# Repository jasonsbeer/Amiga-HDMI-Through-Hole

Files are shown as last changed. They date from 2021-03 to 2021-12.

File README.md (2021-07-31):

# Amiga Video Slot to HDMI with Through Hole Components
This project was inspired by the [Amiga Digital Video](https://github.com/c0pperdragon/Amiga-Digital-Video) project by c0pperdragon. This design makes use of the Amiga 2000/3000 video slot and easy to solder through hole components, making it friendly for even the novice DIYer. At the time of writing this, all the components are available through DigiKey. This has been tested with both standard and Super Denise on Amiga 2000 rev 4.x and 6.x boards. The picture output is outstanding. It should be fully compatable with the Amiga 3000, but I do not have access to one for testing.

There are mounting holes to facilitate the use of a support bracket, which can be 3D printed. The bracket files can be found [here](/STL).

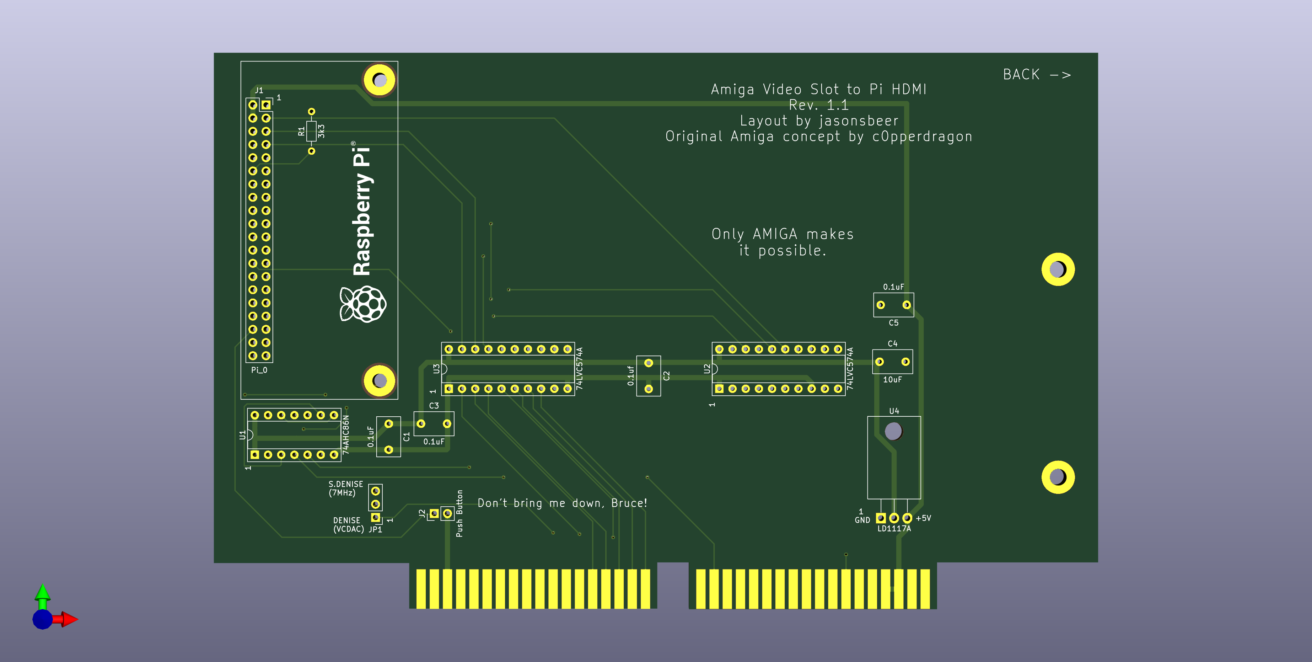
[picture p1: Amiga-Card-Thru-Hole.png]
Video Card Image


## PCB Ordering
The gerber files are available in the [Gerber](/Gerber) folder. Download the file and send to your preferred PCB manufacturer. I've been ordering mine through JLCPCB and have been happy with the results. Most of the options will be set directly from the Gerber file. For the rest, you can select these [options](JLCPCB-1.png).

## PCB Assembly
Order parts from the BOM list. I have included DigiKey part numbers for reference. Solder the components to the board, noting orientation of the sockets. You can solder the chips directly to the board, but I do not recommend this for DIY projects.

### v1.1 BOM
|Component|Package|Location|QTY|Source|Part Number|
--- | --- | --- | --- | --- | ---
SN74AHC86|14-DIP|U1|1|DigiKey|296-4627-5-ND
SN74AHC574|20-DIP|U2-3|2|DigiKey|296-4616-5-ND
LD1117AV33|TO-220-3|U4|1|DigiKey|497-1485-5-ND
14-DIP Socket|14-DIP|U1|1|DigiKey|AE9989-ND
20-DIP Socket|20-DIP|U2-3|2|DigiKey|AE9998-ND
0.1uF Ceramic Capacitor|Radial|C1-3,5|4|DigiKey|399-14065-1-ND
10uF Ceramic Capacitor|Radial|C4|1|DigiKey|445-181284-1-ND
40 Position Female Header|-|J1|1|DigiKey|S6104-ND
3x1 Male Header|-|JP1|1|DigiKey|732-5316-ND
Jumper|-|JP1|1|DigiKey|609-6251-ND
2x1 Male Header|-|J2|1|DigiKey|732-5315-ND
3.3k Resistor|Axial|R1|1|DigiKey|3.3KQBK-ND
Panel Mount HDMI Cable (optional)|-|-|1|DigiKey|1528-1575-ND
HDMI Mini to HDMI Adapter (optional)|-|-|1|DigiKey|1528-2481-ND

## Using The Card
You will need to supply a Raspberry Pi Zero and copy the correct program to a micro-SD card for the Pi to run. The standard (non-W) version of the Pi Zero works fine and is cheaper. You can obtain the current software release from the [RGBtoHDMI](https://github.com/hoglet67/RGBtoHDMI/releases) project page. Click on the link of the newest release, scroll to the bottom of the page, and download the zip file. Unzip and copy the files to the micro SD card and insert the micro SD card in the Pi Zero. Attach the Pi Zero to the video card, making sure to double check the orientation. The Pi Zero should be installed "face down", with pin 1 towards the "top" of the card. Installing the Pi incorrectly will likely kill it.

Set JP1 to match the Denise version in your Amiga. S.Denise = Super Denise (CSG 8373) or Denise (MOS 8362). An incorrect jumper setting will result in a low quality image. Connect an HDMI cable to the Raspberri Pi and to an HDMI or DVI monitor. If you do not have a support bracket, I strongly encourage you to place a peice of thin cardboard between the video card and the power supply of the Amiga 2000. Tape it in place to ensure the card will not short out on the power supply housing.

A momentary push button switch may be attached at J2 that will allow access to settings of the Pi software.

## Revision History
v1.0 Initial production release

v1.1 Routed /C1 and /C3 to U1. Delete U5 and R2

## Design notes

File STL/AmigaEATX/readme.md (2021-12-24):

These are the STL and FreeCAD files used to print a bracket in order to use this card in the Amiga 2000 EATX (https://github.com/jasonsbeer/Amiga-2000-EATX). It includes a mounting for a momentary pushbutton switch (7.2mm cutout) and HDMI panel mount socket.

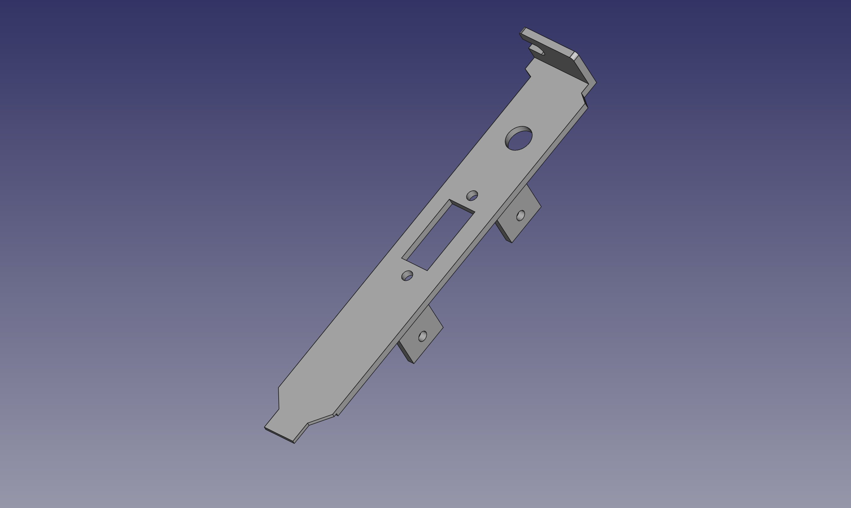
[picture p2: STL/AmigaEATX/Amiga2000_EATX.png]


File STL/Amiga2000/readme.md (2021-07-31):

These are the STL and FreeCAD files for a video slot bracket for this card. Designed specifically for the Amiga 2000, it may also work in an Amiga 3000. It includes a mounting for a momentary pushbutton switch (7.2mm cutout) and HDMI panel mount socket.

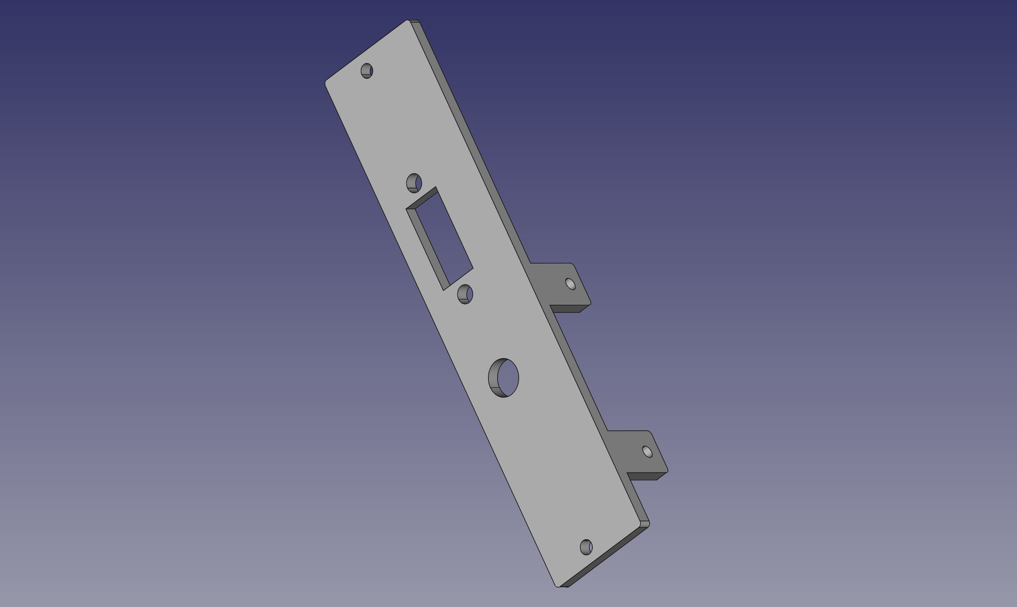
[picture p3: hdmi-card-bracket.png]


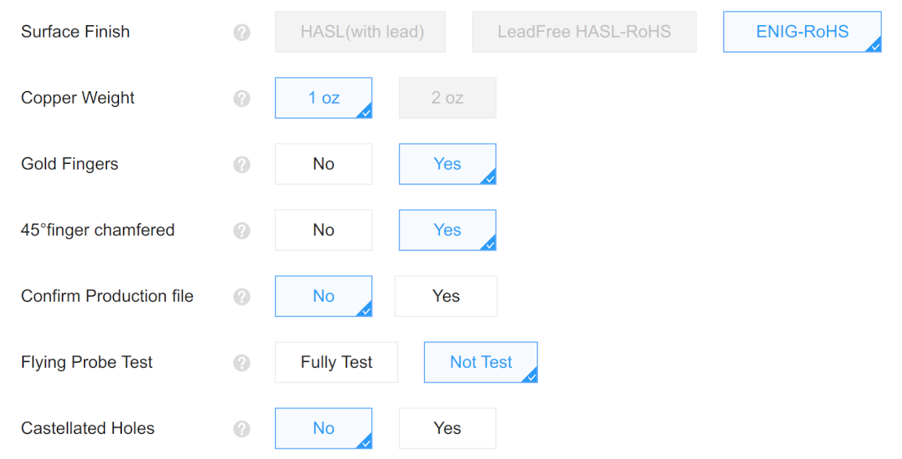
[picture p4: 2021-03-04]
JLCPCB-1.png

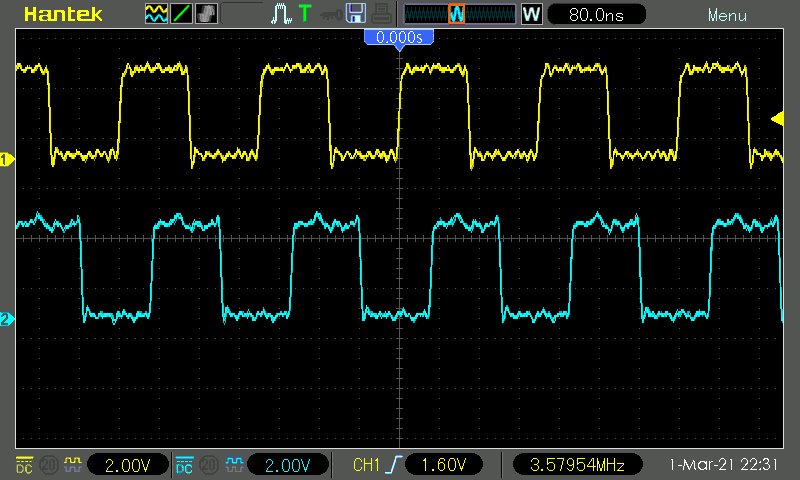
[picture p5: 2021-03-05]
DataSheets/Amiga 2000 C1 and C3 Waveforms.png

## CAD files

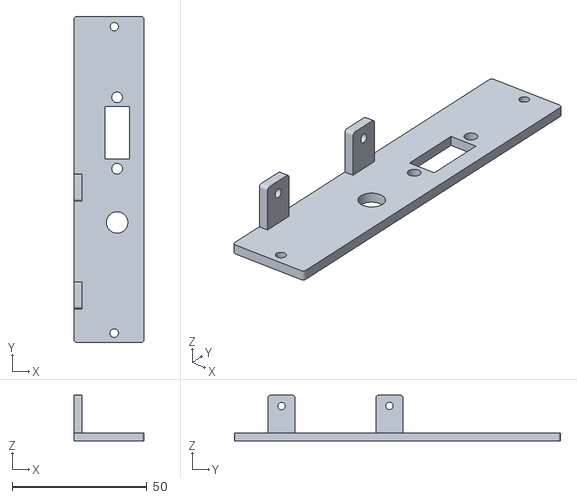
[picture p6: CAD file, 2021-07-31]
STL/Amiga2000/Bracket.stl
26.0 x 121.0 x 17.0

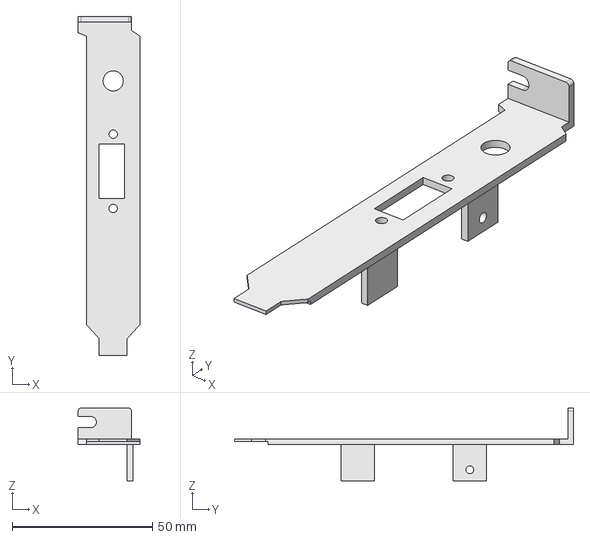
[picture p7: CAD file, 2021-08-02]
STL/AmigaEATX/PIHDMI EATX.FCStd
22.0 x 121.0 x 26.0 mm

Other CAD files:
STL/Amiga2000/VideoSlotPlate.FCStd
STL/AmigaEATX/PIHDMI-EATX-COVER.stl

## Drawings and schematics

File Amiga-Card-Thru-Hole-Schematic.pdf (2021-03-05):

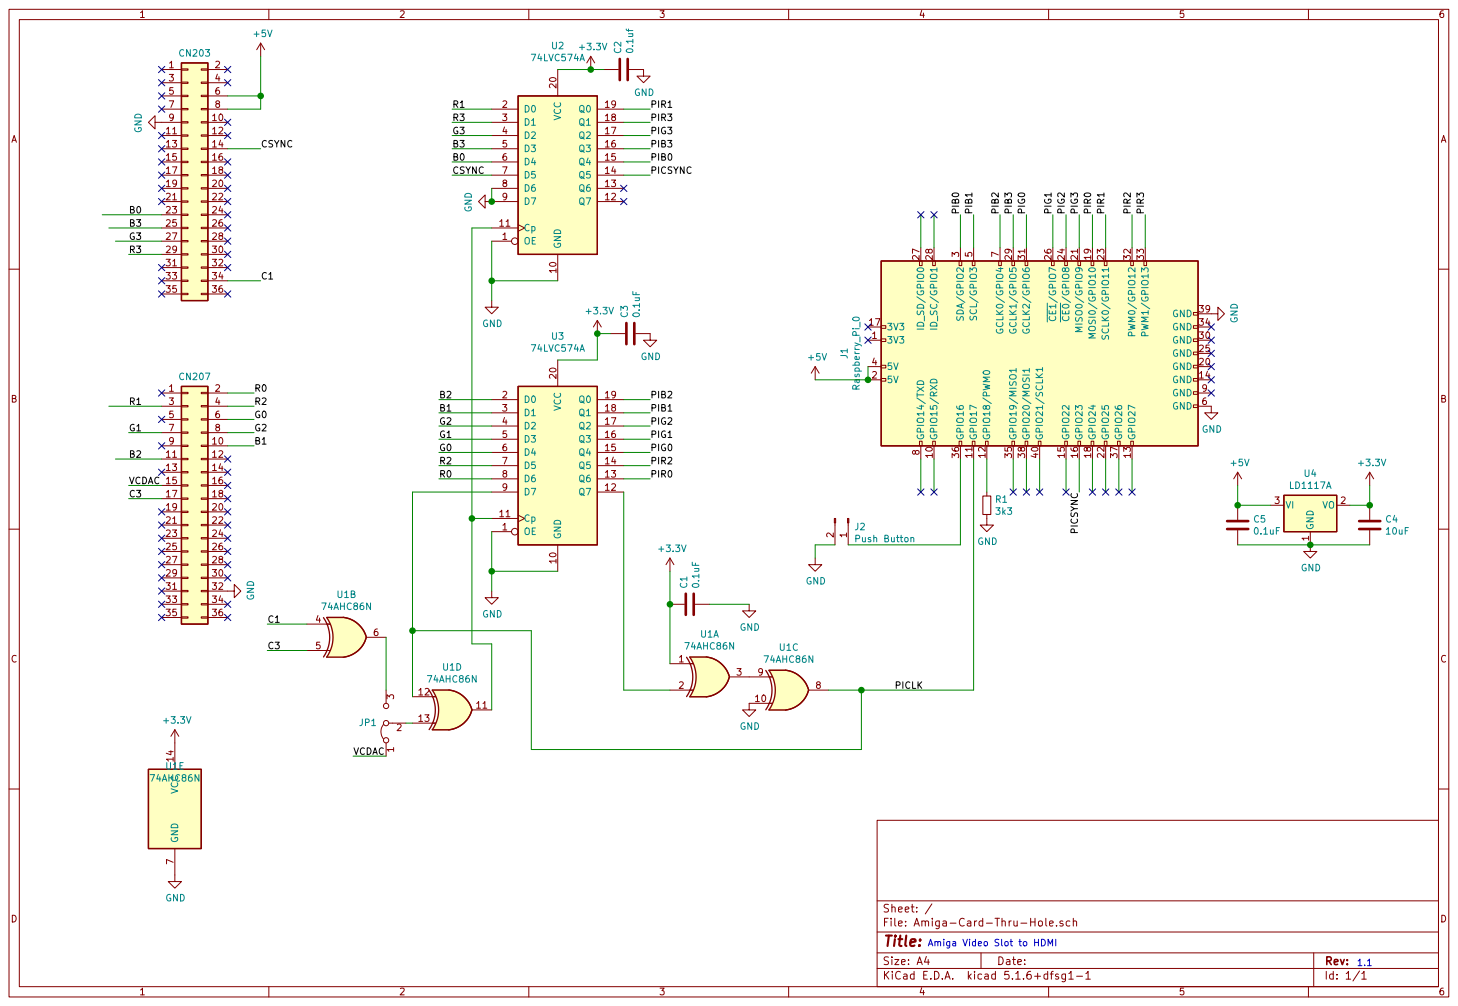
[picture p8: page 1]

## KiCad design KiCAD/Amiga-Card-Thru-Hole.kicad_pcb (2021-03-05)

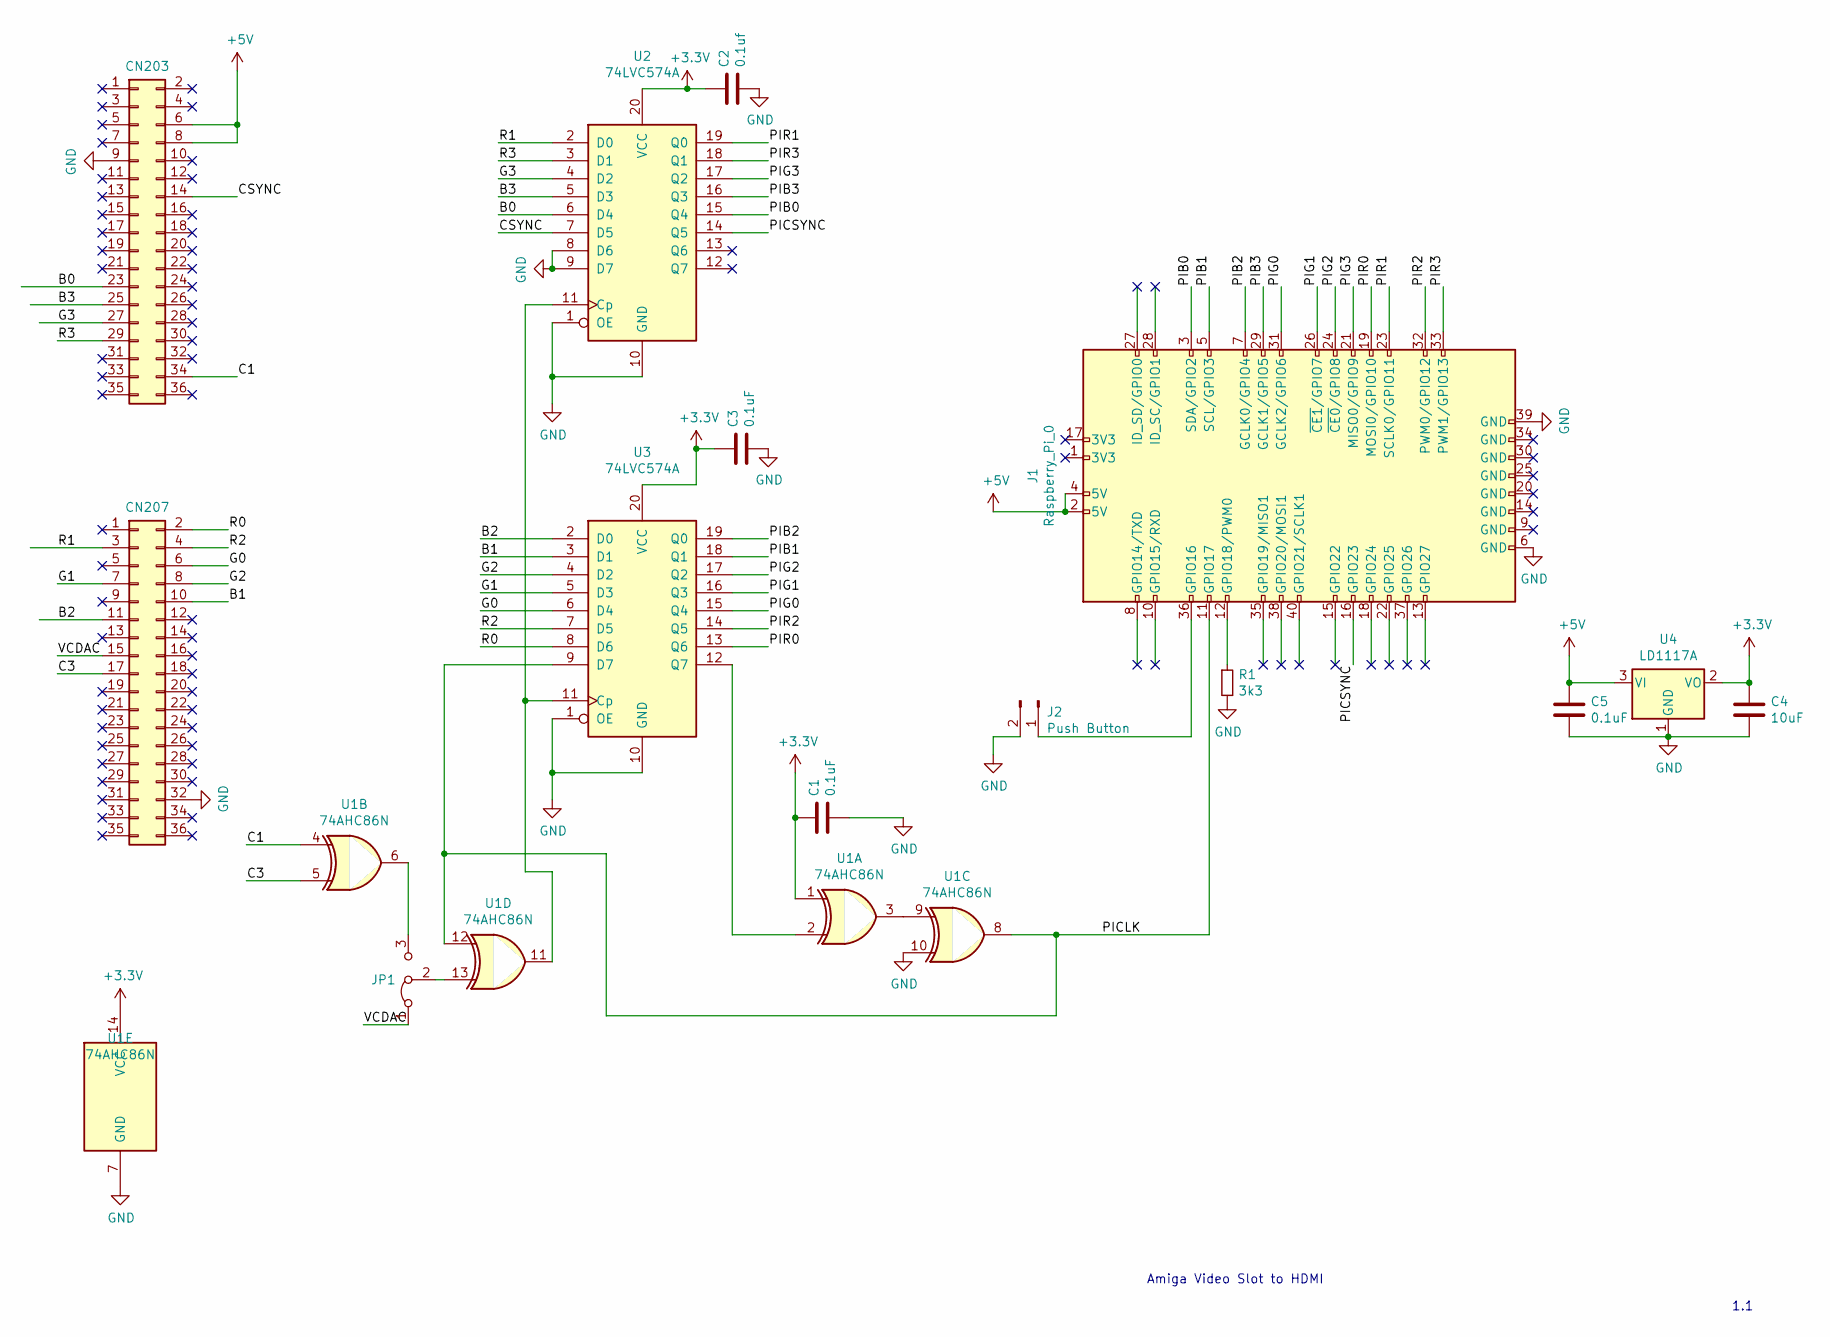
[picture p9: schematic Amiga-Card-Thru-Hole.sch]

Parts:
C1, C3, C5: 0.1uF; C_Disc_D7.5mm_W4.4mm_P5.00mm
C2: 0.1uf; C_Disc_D7.5mm_W4.4mm_P5.00mm
C4: 10uF; C_Disc_D7.5mm_W4.4mm_P5.00mm
CN203: CN203; Amiga 2x18 Card Edge Male
CN207: CN207; Amiga 2x18 Card Edge Male
J1: Raspberry_Pi_0; PinSocket_2x20_P2.54mm_Vertical
J2: Push Button; PinHeader_1x02_P2.54mm_Vertical
JP1: JP1; PinHeader_1x03_P2.54mm_Vertical
R1: 3k3; R_Axial_DIN0204_L3.6mm_D1.6mm_P7.62mm_Horizontal
U1: 74AHC86N; DIP-14_W7.62mm_Socket
U2, U3: 74LVC574A; DIP-20_W7.62mm_Socket
U4: LD1117A; TO-220-3_Horizontal_TabDown

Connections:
+3V3: C1.1, C2.1, C3.1, C4.1, U1.1, U1.14 (VCC), U2.20 (VCC), U3.20 (VCC), U4.2 (VO)
+5V: C5.1, CN203.6, CN203.8, J1.2 (5V), J1.4 (5V), U4.3 (VI)
/B0: CN203.23, U2.6 (D4)
/B1: CN207.10, U3.3 (D1)
/B2: CN207.11, U3.2 (D0)
/B3: CN203.25, U2.5 (D3)
/C1: CN203.34, U1.4
/C3: CN207.17, U1.5
/CSYNC: CN203.14, U2.7 (D5)
/G0: CN207.6, U3.6 (D4)
/G1: CN207.7, U3.5 (D3)
/G2: CN207.8, U3.4 (D2)
/G3: CN203.27, U2.4 (D2)
/PIB0: J1.3 (SDA/GPIO2), U2.15 (Q4)
/PIB1: J1.5 (SCL/GPIO3), U3.18 (Q1)
/PIB2: J1.7 (GCLK0/GPIO4), U3.19 (Q0)
/PIB3: J1.29 (GCLK1/GPIO5), U2.16 (Q3)
/PICLK: J1.11 (GPIO17), U1.8, U1.12, U3.9 (D7)
/PICSYNC: J1.16 (GPIO23), U2.14 (Q5)
/PIG0: J1.31 (GCLK2/GPIO6), U3.15 (Q4)
/PIG1: J1.26 (~CE1~/GPIO7), U3.16 (Q3)
/PIG2: J1.24 (~CE0~/GPIO8), U3.17 (Q2)
/PIG3: J1.21 (MISO0/GPIO9), U2.17 (Q2)
/PIR0: J1.19 (MOSI0/GPIO10), U3.13 (Q6)
/PIR1: J1.23 (SCLK0/GPIO11), U2.19 (Q0)
/PIR2: J1.32 (PWM0/GPIO12), U3.14 (Q5)
/PIR3: J1.33 (PWM1/GPIO13), U2.18 (Q1)
/R0: CN207.2, U3.8 (D6)
/R1: CN207.3, U2.2 (D0)
/R2: CN207.4, U3.7 (D5)
/R3: CN203.29, U2.3 (D1)
/VCDAC: CN207.15, JP1.1 (A)
GND: C1.2, C2.2, C3.2, C4.2, C5.2, CN203.9, CN207.32, J1.6 (GND), J1.39 (GND), J2.2, R1.2, U1.7 (GND), U1.10, U2.1 (OE), U2.8 (D6), U2.9 (D7), U2.10 (GND), U3.1 (OE), U3.10 (GND), U4.1 (GND)
unnamed: J1.12 (GPIO18/PWM0), R1.1
unnamed: J1.36 (GPIO16), J2.1
unnamed: JP1.2 (C), U1.13
unnamed: JP1.3 (B), U1.6
unnamed: U1.2, U3.12 (Q7)
unnamed: U1.3, U1.9
unnamed: U1.11, U2.11 (Cp), U3.11 (Cp)

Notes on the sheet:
1.1
Amiga Video Slot to HDMI

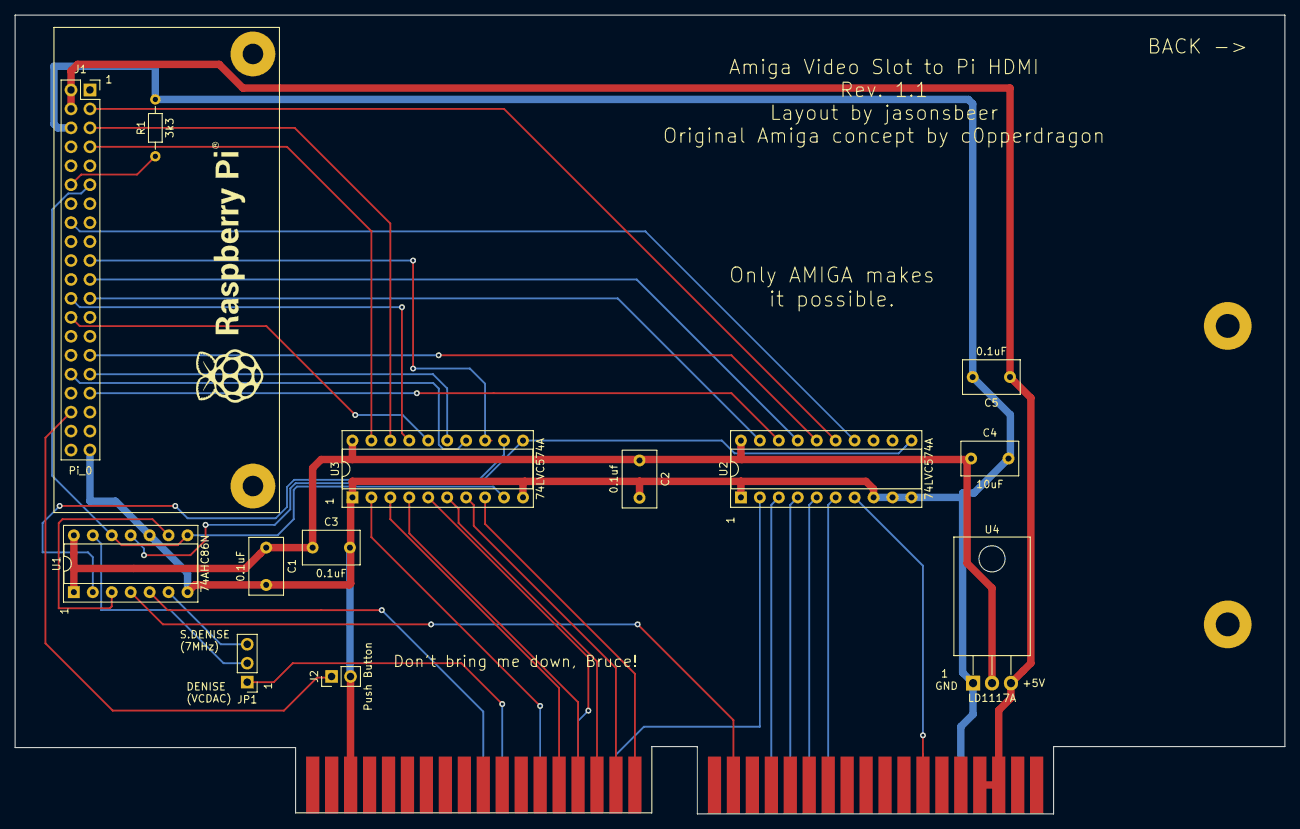
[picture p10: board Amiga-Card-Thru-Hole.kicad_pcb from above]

Board: 2 copper layers, 170.2 x 107.1 mm, 15 parts (0 on the bottom side), 40 nets.
